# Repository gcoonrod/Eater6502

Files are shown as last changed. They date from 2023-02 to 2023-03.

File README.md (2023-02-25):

<!--
 Copyright 2023 Greg Coonrod
 
 Licensed under the Apache License, Version 2.0 (the "License");
 you may not use this file except in compliance with the License.
 You may obtain a copy of the License at
 
     http://www.apache.org/licenses/LICENSE-2.0
 
 Unless required by applicable law or agreed to in writing, software
 distributed under the License is distributed on an "AS IS" BASIS,
 WITHOUT WARRANTIES OR CONDITIONS OF ANY KIND, either express or implied.
 See the License for the specific language governing permissions and
 limitations under the License.
-->

# Eater 6502 - Computer Build

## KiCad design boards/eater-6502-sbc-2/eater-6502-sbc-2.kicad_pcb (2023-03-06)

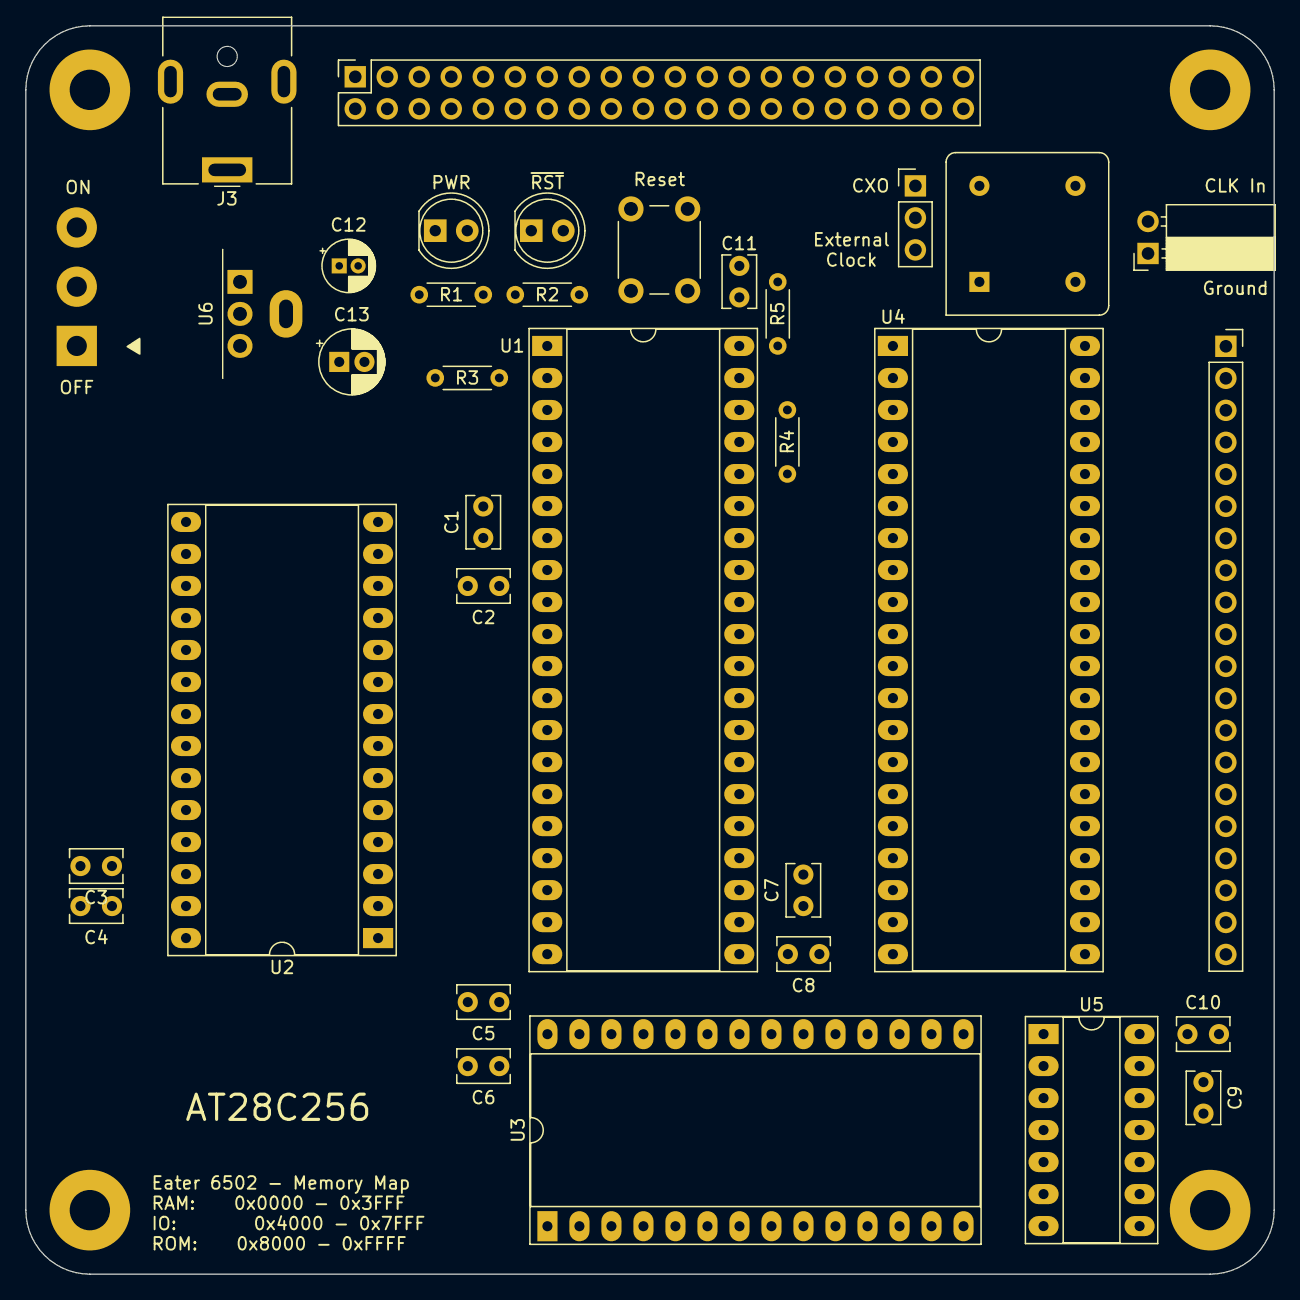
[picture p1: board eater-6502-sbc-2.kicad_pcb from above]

Board: 2 copper layers, 99.1 x 99.1 mm, 39 parts (0 on the bottom side), 70 nets, no tracks yet.

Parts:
C1, C3, C5, C7, C9: 1u; C_Rect_L4.0mm_W2.5mm_P2.50mm
C2, C4, C6, C8, C10, C11: 100n; C_Rect_L4.0mm_W2.5mm_P2.50mm
C12: 0u33; CP_Radial_D4.0mm_P1.50mm
C13: 10u; CP_Radial_D5.0mm_P2.00mm
D1: LED_PWR; LED_D5.0mm
D2: LED_RST; LED_D5.0mm
H1, H2, H3, H4: M3; MountingHole_3.2mm_M3_Pad
HS1: Heatsink; Heatsink_AAVID_576802B03900G
J1: HDR_EXT_CLK; PinSocket_1x02_P2.54mm_Horizontal
J2: HDR_CPU_BUS; PinSocket_2x20_P2.54mm_Vertical
J3: Jack-DC; BarrelJack_CUI_PJ-063AH_Horizontal
J4: HDR_PIO_PORT; PinSocket_1x20_P2.54mm_Vertical
JP1: JMP_CLK; PinHeader_1x03_P2.54mm_Vertical
R1, R2: 470; R_Axial_DIN0204_L3.6mm_D1.6mm_P5.08mm_Horizontal
R3, R4, R5: 1k; R_Axial_DIN0204_L3.6mm_D1.6mm_P5.08mm_Horizontal
SW1: SW_RESET; SW_PUSH_6mm
SW2: SW_PWR; Button_Switch_SPST_NKK_CS12ANW03
U1: W65C02SxP; DIP-40_W15.24mm_Socket_LongPads
U2: 28C256; DIP-28_W15.24mm_Socket_LongPads
U3: KM62256CLP; DIP-28_W15.24mm_Socket_LongPads
U4: W65C22NxP; DIP-40_W15.24mm_Socket_LongPads
U5: 74HC132; DIP-14_W7.62mm_Socket_LongPads
U6: MC7805; TO-220-3_Vertical
X1: 14 MHz; Oscillator_DIP-8

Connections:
/A0: J2.17, U1.9 (A0), U2.10 (A0), U3.10 (A0), U4.38 (RS0)
/A1: J2.19, U1.10 (A1), U2.9 (A1), U3.9 (A1), U4.37 (RS1)
/A2: J2.21, U1.11 (A2), U2.8 (A2), U3.8 (A2), U4.36 (RS2)
/A3: J2.23, U1.12 (A3), U2.7 (A3), U3.7 (A3), U4.35 (RS3)
/A4: J2.25, U1.13 (A4), U2.6 (A4), U3.6 (A4)
/A5: J2.27, U1.14 (A5), U2.5 (A5), U3.5 (A5)
/A6: J2.29, U1.15 (A6), U2.4 (A6), U3.4 (A6)
/A7: J2.31, U1.16 (A7), U2.3 (A7), U3.3 (A7)
/A8: J2.33, U1.17 (A8), U2.25 (A8), U3.25 (A8)
/A9: J2.35, U1.18 (A9), U2.24 (A9), U3.24 (A9)
/A10: J2.37, U1.19 (A10), U2.21 (A10), U3.21 (A10)
/A11: J2.39, U1.20 (A11), U2.23 (A11), U3.23 (A11)
/A12: J2.38, U1.22 (A12), U2.2 (A12), U3.2 (A12)
/A13: J2.36, U1.23 (A13), U2.26 (A13), U3.26 (A13), U4.24 (CS1)
/A14: J2.34, U1.24 (A14), U2.1 (A14), U3.1 (A14), U3.22 (~OE), U5.5
/A15: J2.32, U1.25 (A15), U5.1, U5.2
/ADDR_~HI: U2.20 (~CS), U5.3, U5.4, U5.9
/BE: J2.10, R4.1, U1.36 (BE)
/CA1: J4.9, U4.40 (CA1)
/CA2: J4.10, U4.39 (CA2)
/CB1: J4.11, U4.18 (CB1)
/CB2: J4.12, U4.19 (CB2)
/CLK: J2.8, JP1.2 (C), U1.37 (ϕ0), U4.25 (ϕ2), U5.10
/CLK2: J2.4, U1.39 (ϕ2)
/CXO: JP1.1 (A), X1.5 (OUT)
/D0: J2.16, U1.33 (D0), U2.11 (D0), U3.11 (Q0), U4.33 (D0)
/D1: J2.18, U1.32 (D1), U2.12 (D1), U3.12 (Q1), U4.32 (D1)
/D2: J2.20, U1.31 (D2), U2.13 (D2), U3.13 (Q2), U4.31 (D2)
/D3: J2.22, U1.30 (D3), U2.15 (D3), U3.15 (Q3), U4.30 (D3)
/D4: J2.24, U1.29 (D4), U2.16 (D4), U3.16 (Q4), U4.29 (D4)
/D5: J2.26, U1.28 (D5), U2.17 (D5), U3.17 (Q5), U4.28 (D5)
/D6: J2.28, U1.27 (D6), U2.18 (D6), U3.18 (Q6), U4.27 (D6)
/D7: J2.30, U1.26 (D7), U2.19 (D7), U3.19 (Q7), U4.26 (D7)
/EXT_CLK: J1.2, JP1.3 (B)
/PA0: J4.1, U4.2 (PA0)
/PA1: J4.2, U4.3 (PA1)
/PA2: J4.3, U4.4 (PA2)
/PA3: J4.4, U4.5 (PA3)
/PA4: J4.5, U4.6 (PA4)
/PA5: J4.6, U4.7 (PA5)
/PA6: J4.7, U4.8 (PA6)
/PA7: J4.8, U4.9 (PA7)
/PB0: J4.13, U4.10 (PB0)
/PB1: J4.14, U4.11 (PB1)
/PB2: J4.15, U4.12 (PB2)
/PB3: J4.16, U4.13 (PB3)
/PB4: J4.17, U4.14 (PB4)
/PB5: J4.18, U4.15 (PB5)
/PB6: J4.19, U4.16 (PB6)
/PB7: J4.20, U4.17 (PB7)
/RAM_~EN: U3.20 (~CS), U5.8
/RDY: J2.3, R3.2, U1.2 (RDY)
/R/~W: J2.14, U1.34 (R/~W), U3.27 (~WE), U4.22 (R/~W)
/SYNC: J2.13, U1.7 (SYNC)
/VIA_~CS2: U4.23 (~CS2), U5.6
/~CLK: J2.5, U1.3 (ϕ1)
/~IRQ: J2.7, U1.4 (~IRQ), U4.21 (~IRQ)
/~ML: J2.9, U1.5 (~ML)
/~NMI: J2.11, U1.6 (~NMI)
/~RES: J2.2, U1.40 (~RES), U4.34 (~RES), U5.12, U5.13
/~RST: C11.2, R5.2, SW1.2
/~SO: J2.6, U1.38 (~SO)
/~VP: J2.1, U1.1 (~VP)
GND: C1.2, C2.2, C3.2, C4.2, C5.2, C6.2, C7.2, C8.2, C9.2, C10.2, C11.1, C12.2, C13.2, H1.1, H2.1, H3.1, H4.1, J1.1, J2.40, J3.2, R1.2, R2.2, SW1.1, U1.21 (VSS), U2.14 (GND), U2.22 (~OE), U3.14 (GND), U4.1 (VSS), U5.7 (GND), U6.2 (GND), X1.4 (GND)
unnamed: D1.1 (K), R1.1
unnamed: D2.1 (K), R2.1
unnamed: D2.2 (A), U5.11
unnamed: J3.1, SW2.2 (B)
VCC: C1.1, C2.1, C3.1, C4.1, C5.1, C6.1, C7.1, C8.1, C9.1, C10.1, C13.1, D1.2 (A), J2.15, R3.1, R4.2, R5.1, U1.8 (VDD), U2.27 (~WE), U2.28 (VCC), U3.28 (VCC), U4.20 (VCC), U5.14 (VCC), U6.3 (VO), X1.8 (Vcc)
VDC: C12.1, SW2.3 (C), U6.1 (VI)

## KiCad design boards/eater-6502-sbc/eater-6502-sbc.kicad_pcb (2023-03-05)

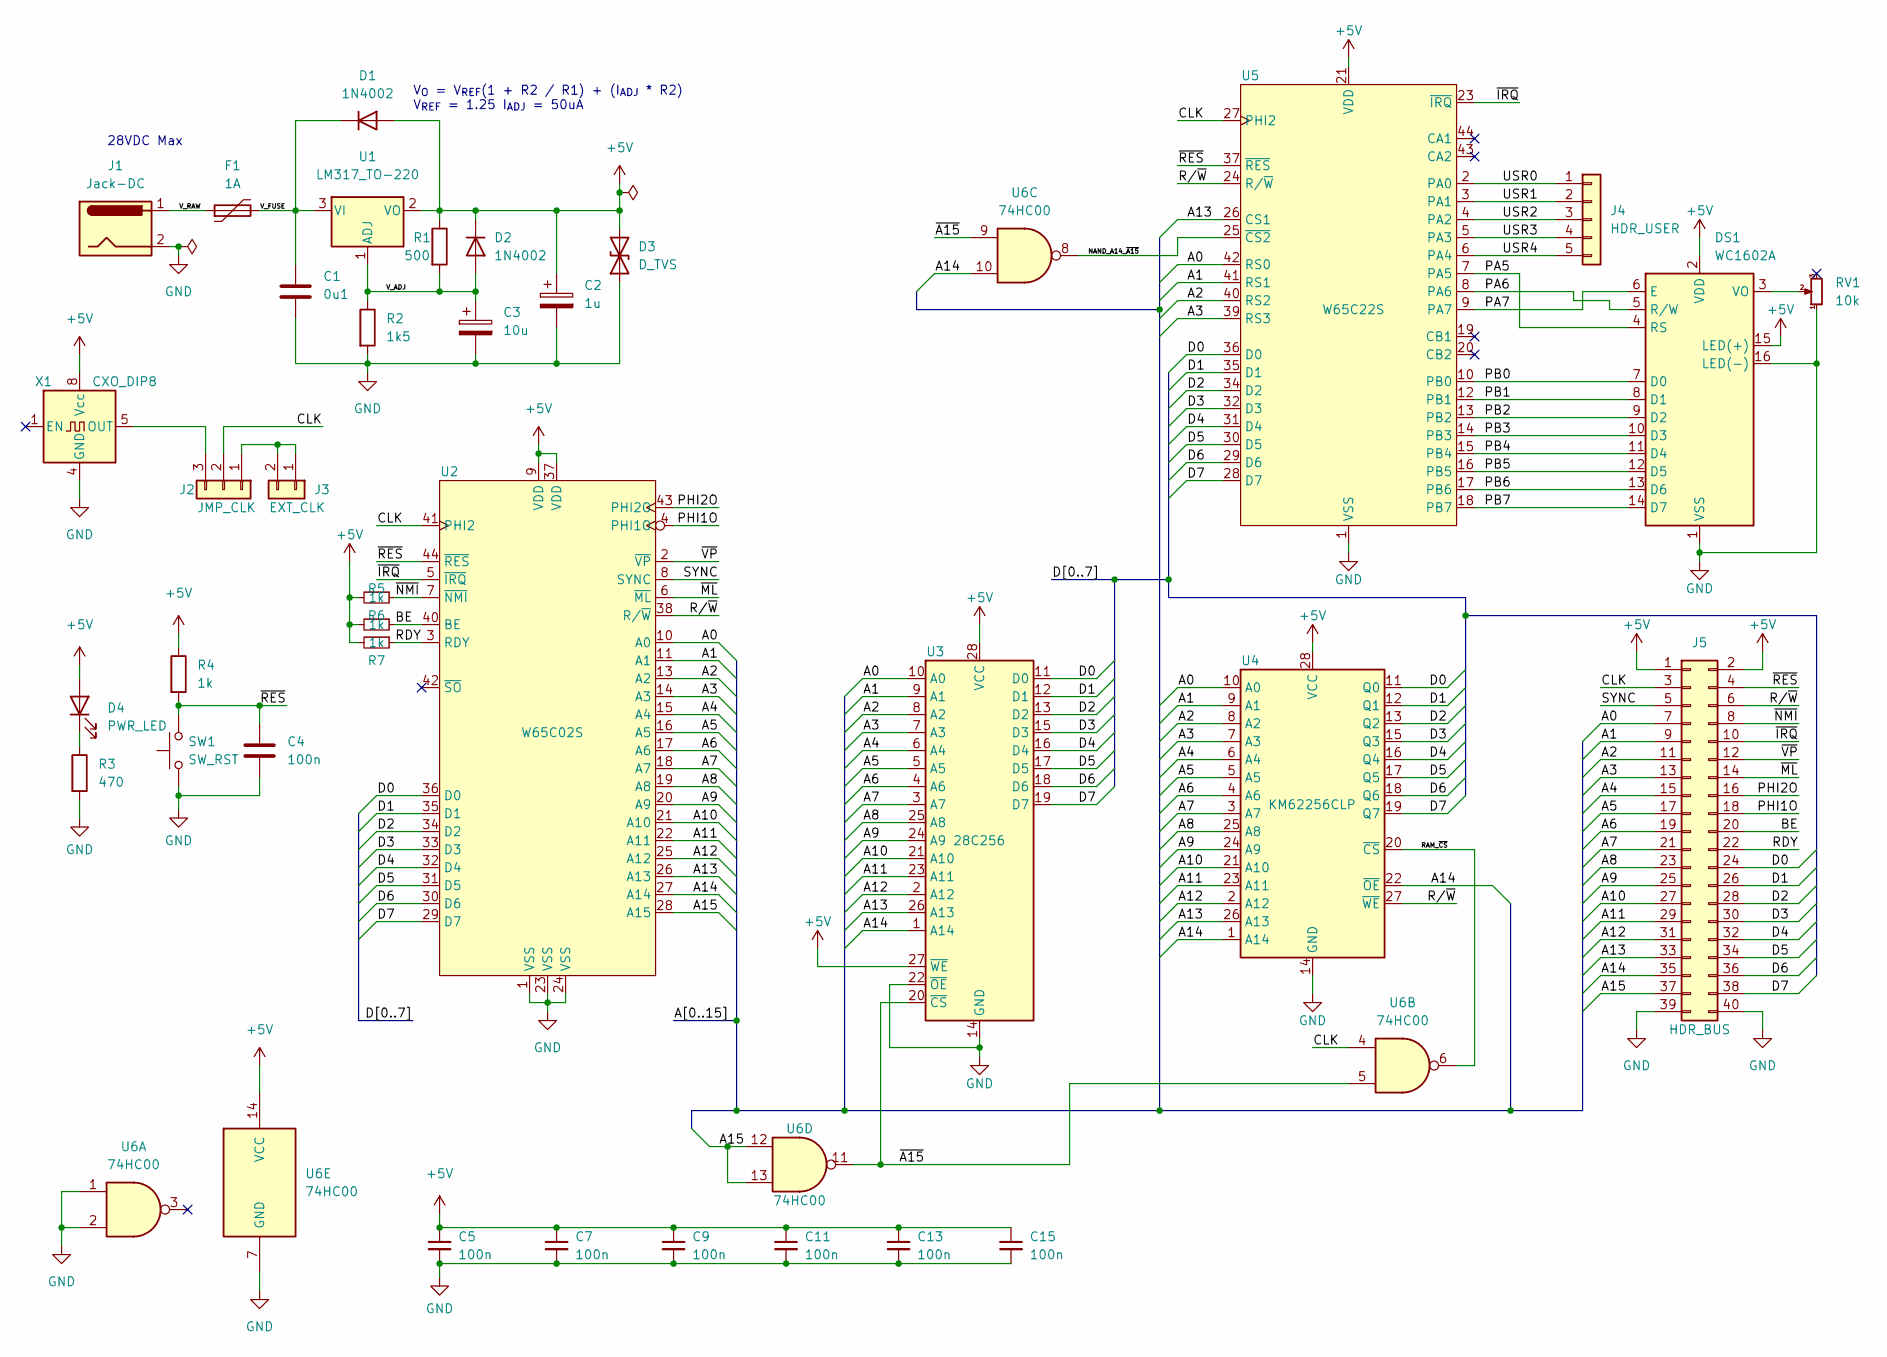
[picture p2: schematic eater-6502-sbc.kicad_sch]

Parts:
C1: 0u1; C_Disc_D3.4mm_W2.1mm_P2.50mm
C2: 1u; CP_Radial_D4.0mm_P1.50mm
C3: 10u; CP_Radial_D5.0mm_P2.00mm
C4, C5, C7, C9, C11, C13, C15: 100n; C_Disc_D3.4mm_W2.1mm_P2.50mm
D1, D2: 1N4002; D_DO-41_SOD81_P10.16mm_Horizontal
D3: D_TVS; D_DO-41_SOD81_P7.62mm_Horizontal
D4: PWR_LED; LED_D5.0mm
DS1: WC1602A
F1: 1A; Fuse_BelFuse_0ZRE0005FF_L8.3mm_W3.8mm
J1: Jack-DC; BarrelJack_CUI_PJ-063AH_Horizontal
J2: JMP_CLK; PinHeader_1x03_P2.54mm_Vertical
J3: EXT_CLK; PinSocket_1x02_P2.54mm_Vertical
J4: HDR_USER; PinSocket_1x05_P2.54mm_Vertical
J5: HDR_BUS; PinSocket_2x20_P2.54mm_Vertical
R1: 500; R_Axial_DIN0207_L6.3mm_D2.5mm_P10.16mm_Horizontal
R2: 1k5; R_Axial_DIN0207_L6.3mm_D2.5mm_P10.16mm_Horizontal
R3: 470; R_Axial_DIN0204_L3.6mm_D1.6mm_P5.08mm_Horizontal
R4, R5, R6, R7: 1k; R_Axial_DIN0204_L3.6mm_D1.6mm_P5.08mm_Horizontal
RV1: 10k; Potentiometer_Bourns_3266W_Vertical
SW1: SW_RST; SW_PUSH_6mm
U1: LM317_TO-220; TO-220-3_Vertical; Manufacturer Part Number LM317KCS
U2: W65C02S; PLCC-44_THT-Socket; Manufacturer Part Number W65C02S6TPLG-14
U3: 28C256; DIP_Socket-28_W11.9_W12.7_W15.24_W17.78_W18.5_3M_228-1277-0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; Manufacturer Part Number 28-6554-10
U4: KM62256CLP; DIP-28_W15.24mm_Socket_LongPads; Manufacturer Part Number AS6C62256-55PCN
U5: W65C22S; PLCC-44_THT-Socket; Manufacturer Part Number W65C22S6TPLG-14
U6: 74HC00; DIP-14_W7.62mm_LongPads
X1: CXO_DIP8; Oscillator_DIP-8_LargePads

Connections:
+5V: C2.1, C5.1, C7.1, C9.1, C11.1, C13.1, C15.1, D1.2 (A), D2.1 (K), D3.2 (A2), D4.2 (A), DS1.2 (VDD), DS1.15 (LED(+)), J5.1, J5.2, R1.1, R4.1, R5.2, R6.2, R7.2, U1.2 (VO), U2.9 (VDD), U2.37 (VDD), U3.27 (~WE), U3.28 (VCC), U4.28 (VCC), U5.21 (VDD), U6.14 (VCC), X1.8 (Vcc)
/A0: J5.7, U2.10 (A0), U3.10 (A0), U4.10 (A0), U5.42 (RS0)
/A1: J5.9, U2.11 (A1), U3.9 (A1), U4.9 (A1), U5.41 (RS1)
/A2: J5.11, U2.13 (A2), U3.8 (A2), U4.8 (A2), U5.40 (RS2)
/A3: J5.13, U2.14 (A3), U3.7 (A3), U4.7 (A3), U5.39 (RS3)
/A4: J5.15, U2.15 (A4), U3.6 (A4), U4.6 (A4)
/A5: J5.17, U2.16 (A5), U3.5 (A5), U4.5 (A5)
/A6: J5.19, U2.17 (A6), U3.4 (A6), U4.4 (A6)
/A7: J5.21, U2.18 (A7), U3.3 (A7), U4.3 (A7)
/A8: J5.23, U2.19 (A8), U3.25 (A8), U4.25 (A8)
/A9: J5.25, U2.20 (A9), U3.24 (A9), U4.24 (A9)
/A10: J5.27, U2.21 (A10), U3.21 (A10), U4.21 (A10)
/A11: J5.29, U2.22 (A11), U3.23 (A11), U4.23 (A11)
/A12: J5.31, U2.25 (A12), U3.2 (A12), U4.2 (A12)
/A13: J5.33, U2.26 (A13), U3.26 (A13), U4.26 (A13), U5.26 (CS1)
/A14: J5.35, U2.27 (A14), U3.1 (A14), U4.1 (A14), U4.22 (~OE), U6.10
/A15: J5.37, U2.28 (A15), U6.12, U6.13
/BE: J5.20, R6.1, U2.40 (BE)
/CLK: J2.2, J5.3, U2.41 (PHI2), U5.27 (PHI2), U6.4
/D0: J5.24, U2.36 (D0), U3.11 (D0), U4.11 (Q0), U5.36 (D0)
/D1: J5.26, U2.35 (D1), U3.12 (D1), U4.12 (Q1), U5.35 (D1)
/D2: J5.28, U2.34 (D2), U3.13 (D2), U4.13 (Q2), U5.34 (D2)
/D3: J5.30, U2.33 (D3), U3.15 (D3), U4.15 (Q3), U5.32 (D3)
/D4: J5.32, U2.32 (D4), U3.16 (D4), U4.16 (Q4), U5.31 (D4)
/D5: J5.34, U2.31 (D5), U3.17 (D5), U4.17 (Q5), U5.30 (D5)
/D6: J5.36, U2.30 (D6), U3.18 (D6), U4.18 (Q6), U5.29 (D6)
/D7: J5.38, U2.29 (D7), U3.19 (D7), U4.19 (Q7), U5.28 (D7)
/NAND_A14_~A15: U5.25 (~CS2), U6.8
/PA5: DS1.4 (RS), U5.7 (PA5)
/PA6: DS1.5 (R/W), U5.8 (PA6)
/PA7: DS1.6 (E), U5.9 (PA7)
/PB0: DS1.7 (D0), U5.10 (PB0)
/PB1: DS1.8 (D1), U5.12 (PB1)
/PB2: DS1.9 (D2), U5.13 (PB2)
/PB3: DS1.10 (D3), U5.14 (PB3)
/PB4: DS1.11 (D4), U5.15 (PB4)
/PB5: DS1.12 (D5), U5.16 (PB5)
/PB6: DS1.13 (D6), U5.17 (PB6)
/PB7: DS1.14 (D7), U5.18 (PB7)
/PHI1O: J5.18, U2.4 (PHI1O)
/PHI2O: J5.16, U2.43 (PHI2O)
/RAM_~CS: U4.20 (~CS), U6.6
/RDY: J5.22, R7.1, U2.3 (RDY)
/R/~W: J5.6, U2.38 (R/~W), U4.27 (~WE), U5.24 (R/~W)
/SYNC: J5.5, U2.8 (SYNC)
/USR0: J4.1, U5.2 (PA0)
/USR1: J4.2, U5.3 (PA1)
/USR2: J4.3, U5.4 (PA2)
/USR3: J4.4, U5.5 (PA3)
/USR4: J4.5, U5.6 (PA4)
/V_ADJ: C3.1, D2.2 (A), R1.2, R2.1, U1.1 (ADJ)
/V_FUSE: C1.1, D1.1 (K), F1.2, U1.3 (VI)
/V_RAW: F1.1, J1.1
/~A15: U3.20 (~CS), U6.5, U6.9, U6.11
/~IRQ: J5.10, U2.5 (~IRQ), U5.23 (~IRQ)
/~ML: J5.14, U2.6 (~ML)
/~NMI: J5.8, R5.1, U2.7 (~NMI)
/~RES: C4.1, J5.4, R4.2, SW1.2, U2.44 (~RES), U5.37 (~RES)
/~VP: J5.12, U2.2 (~VP)
GND: C1.2, C2.2, C3.2, C4.2, C5.2, C7.2, C9.2, C11.2, C13.2, C15.2, D3.1 (A1), DS1.1 (VSS), DS1.16 (LED(-)), J1.2, J5.39, J5.40, R2.2, R3.2, RV1.1, SW1.1, U2.1 (VSS), U2.23 (VSS), U2.24 (VSS), U3.14 (GND), U3.22 (~OE), U4.14 (GND), U5.1 (VSS), U6.1, U6.2, U6.7 (GND), X1.4 (GND)
unnamed: D4.1 (K), R3.1
unnamed: DS1.3 (VO), RV1.2
unnamed: J2.1, J3.1, J3.2
unnamed: J2.3, X1.5 (OUT)

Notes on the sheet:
V_{O} = V_{REF}(1 + R2 / R1) + (I_{ADJ} * R2) V_{REF} = 1.25 I_{ADJ} = 50uA
28VDC Max

Board: 2 copper layers, 37 parts (0 on the bottom side), 64 nets, no tracks yet.

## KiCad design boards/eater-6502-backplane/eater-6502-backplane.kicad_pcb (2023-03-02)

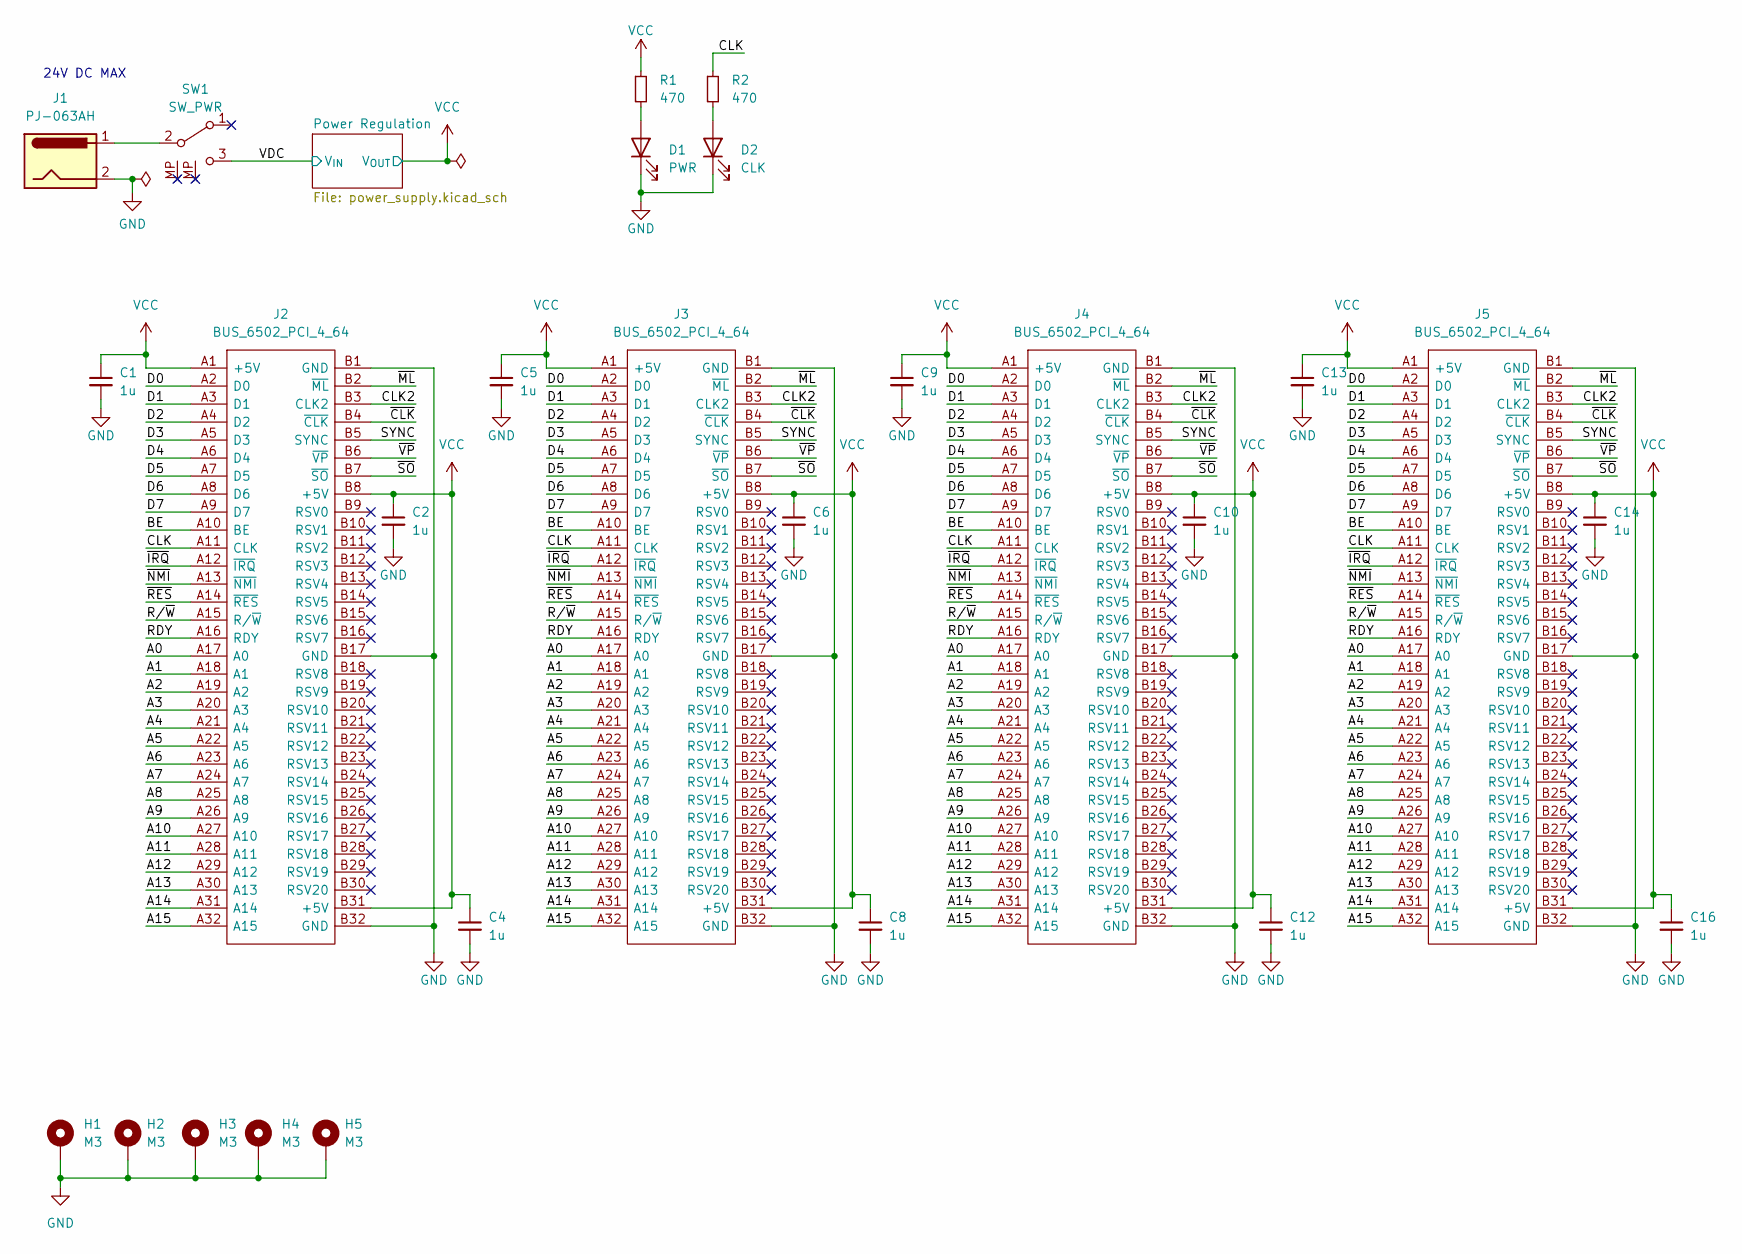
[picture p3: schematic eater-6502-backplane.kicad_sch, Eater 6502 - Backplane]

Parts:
C1, C2, C4, C5, C6, C8, C9, C10, C12, C13, C14, C16: 1u; C_Rect_L4.0mm_W2.5mm_P2.50mm; Manufacturer Part Number FG18X5R1H105KRT06
D1: PWR; LED_D5.0mm
D2: CLK; LED_D5.0mm
H1, H2, H3, H4, H5: M3; MountingHole_3.2mm_M3_Pad_Via
J1: PJ-063AH; BarrelJack_CUI_PJ-063AH_Horizontal; Manufacturer Part Number PJ-063AH
J2, J3, J4, J5: BUS_6502_PCI_4_64; 877159100 PCIe x4; Mouser Part Number 538-87715-9100
R1, R2: 470; R_Axial_DIN0207_L6.3mm_D2.5mm_P7.62mm_Horizontal; Manufacturer Part Number RNF14FTD470R
SW1: SW_PWR; Button_Switch_Dailywell_SPDT; Manufacturer Part Number 5MS1S102AM6QES

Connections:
/A0: J2.A17 (A0), J3.A17 (A0), J4.A17 (A0), J5.A17 (A0)
/A1: J2.A18 (A1), J3.A18 (A1), J4.A18 (A1), J5.A18 (A1)
/A2: J2.A19 (A2), J3.A19 (A2), J4.A19 (A2), J5.A19 (A2)
/A3: J2.A20 (A3), J3.A20 (A3), J4.A20 (A3), J5.A20 (A3)
/A4: J2.A21 (A4), J3.A21 (A4), J4.A21 (A4), J5.A21 (A4)
/A5: J2.A22 (A5), J3.A22 (A5), J4.A22 (A5), J5.A22 (A5)
/A6: J2.A23 (A6), J3.A23 (A6), J4.A23 (A6), J5.A23 (A6)
/A7: J2.A24 (A7), J3.A24 (A7), J4.A24 (A7), J5.A24 (A7)
/A8: J2.A25 (A8), J3.A25 (A8), J4.A25 (A8), J5.A25 (A8)
/A9: J2.A26 (A9), J3.A26 (A9), J4.A26 (A9), J5.A26 (A9)
/A10: J2.A27 (A10), J3.A27 (A10), J4.A27 (A10), J5.A27 (A10)
/A11: J2.A28 (A11), J3.A28 (A11), J4.A28 (A11), J5.A28 (A11)
/A12: J2.A29 (A12), J3.A29 (A12), J4.A29 (A12), J5.A29 (A12)
/A13: J2.A30 (A13), J3.A30 (A13), J4.A30 (A13), J5.A30 (A13)
/A14: J2.A31 (A14), J3.A31 (A14), J4.A31 (A14), J5.A31 (A14)
/A15: J2.A32 (A15), J3.A32 (A15), J4.A32 (A15), J5.A32 (A15)
/BE: J2.A10 (BE), J3.A10 (BE), J4.A10 (BE), J5.A10 (BE)
/CLK: J2.A11 (CLK), J3.A11 (CLK), J4.A11 (CLK), J5.A11 (CLK), R2.1
/CLK2: J2.B3 (CLK2), J3.B3 (CLK2), J4.B3 (CLK2), J5.B3 (CLK2)
/D0: J2.A2 (D0), J3.A2 (D0), J4.A2 (D0), J5.A2 (D0)
/D1: J2.A3 (D1), J3.A3 (D1), J4.A3 (D1), J5.A3 (D1)
/D2: J2.A4 (D2), J3.A4 (D2), J4.A4 (D2), J5.A4 (D2)
/D3: J2.A5 (D3), J3.A5 (D3), J4.A5 (D3), J5.A5 (D3)
/D4: J2.A6 (D4), J3.A6 (D4), J4.A6 (D4), J5.A6 (D4)
/D5: J2.A7 (D5), J3.A7 (D5), J4.A7 (D5), J5.A7 (D5)
/D6: J2.A8 (D6), J3.A8 (D6), J4.A8 (D6), J5.A8 (D6)
/D7: J2.A9 (D7), J3.A9 (D7), J4.A9 (D7), J5.A9 (D7)
/RDY: J2.A16 (RDY), J3.A16 (RDY), J4.A16 (RDY), J5.A16 (RDY)
/R/~W: J2.A15 (R/~W), J3.A15 (R/~W), J4.A15 (R/~W), J5.A15 (R/~W)
/SYNC: J2.B5 (SYNC), J3.B5 (SYNC), J4.B5 (SYNC), J5.B5 (SYNC)
/VDC: SW1.3 (C); also elsewhere on the board
/~CLK: J2.B4 (~CLK), J3.B4 (~CLK), J4.B4 (~CLK), J5.B4 (~CLK)
/~IRQ: J2.A12 (~IRQ), J3.A12 (~IRQ), J4.A12 (~IRQ), J5.A12 (~IRQ)
/~ML: J2.B2 (~ML), J3.B2 (~ML), J4.B2 (~ML), J5.B2 (~ML)
/~NMI: J2.A13 (~NMI), J3.A13 (~NMI), J4.A13 (~NMI), J5.A13 (~NMI)
/~RES: J2.A14 (~RES), J3.A14 (~RES), J4.A14 (~RES), J5.A14 (~RES)
/~SO: J2.B7 (~SO), J3.B7 (~SO), J4.B7 (~SO), J5.B7 (~SO)
/~VP: J2.B6 (~VP), J3.B6 (~VP), J4.B6 (~VP), J5.B6 (~VP)
GND: C1.2, C2.2, C4.2, C5.2, C6.2, C8.2, C9.2, C10.2, C12.2, C13.2, C14.2, C16.2, D1.1 (K), D2.1 (K), H1.1, H2.1, H3.1, H4.1, H5.1, J1.2, J2.B1 (GND), J2.B17 (GND), J2.B32 (GND), J3.B1 (GND), J3.B17 (GND), J3.B32 (GND), J4.B1 (GND), J4.B17 (GND), J4.B32 (GND), J5.B1 (GND), J5.B17 (GND), J5.B32 (GND); also elsewhere on the board
unnamed: D1.2 (A), R1.2
unnamed: D2.2 (A), R2.2
unnamed: J1.1, SW1.2 (B)
VCC: C1.1, C2.1, C4.1, C5.1, C6.1, C8.1, C9.1, C10.1, C12.1, C13.1, C14.1, C16.1, J2.A1 (+5V), J2.B8 (+5V), J2.B31 (+5V), J3.A1 (+5V), J3.B8 (+5V), J3.B31 (+5V), J4.A1 (+5V), J4.B8 (+5V), J4.B31 (+5V), J5.A1 (+5V), J5.B8 (+5V), J5.B31 (+5V), R1.1; also elsewhere on the board

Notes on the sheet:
24V DC MAX

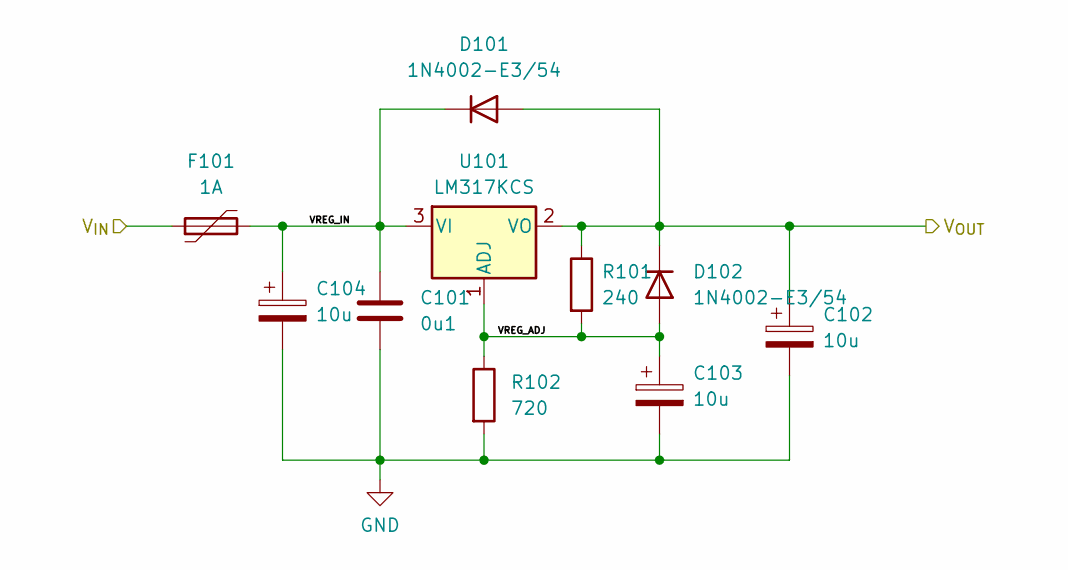
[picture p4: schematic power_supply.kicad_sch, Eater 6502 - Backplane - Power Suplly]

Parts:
C101: 0u1; C_Disc_D4.3mm_W1.9mm_P5.00mm; Manufacturer Part Number K104K15X7RF5TH5
C102, C103, C104: 10u; CP_Radial_D5.0mm_P2.00mm; Manufacturer Part Number 860010572002
D101, D102: 1N4002-E3/54; D_DO-41_SOD81_P10.16mm_Horizontal; Manufacturer Part Number 1N4002-E3/54
F101: 1A; Fuse_BelFuse_0ZRE0025FF_L9.6mm_W3.8mm; Manufacturer Part Number 0ZRM0050FF1E
R101: 240; R_Axial_DIN0207_L6.3mm_D2.5mm_P10.16mm_Horizontal; Manufacturer Part Number SFR2500002400FR500
R102: 720; R_Axial_DIN0207_L6.3mm_D2.5mm_P10.16mm_Horizontal; Manufacturer Part Number MFR-25FTF52-720R
U101: LM317KCS; TO-220-3_Vertical; Manufacturer Part Number LM317KCS

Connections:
/Power Regulation/VREG_ADJ: C103.1, D102.2 (A), R101.2, R102.1, U101.1 (ADJ)
/Power Regulation/VREG_IN: C101.1, C104.1, D101.1 (K), F101.2, U101.3 (VI)
/VDC: F101.1; also elsewhere on the board
GND: C101.2, C102.2, C103.2, C104.2, R102.2; also elsewhere on the board
VCC: C102.1, D101.2 (A), D102.1 (K), R101.1, U101.2 (VO); also elsewhere on the board

Board: 2 copper layers, 37 parts (0 on the bottom side), 45 nets, no tracks yet.

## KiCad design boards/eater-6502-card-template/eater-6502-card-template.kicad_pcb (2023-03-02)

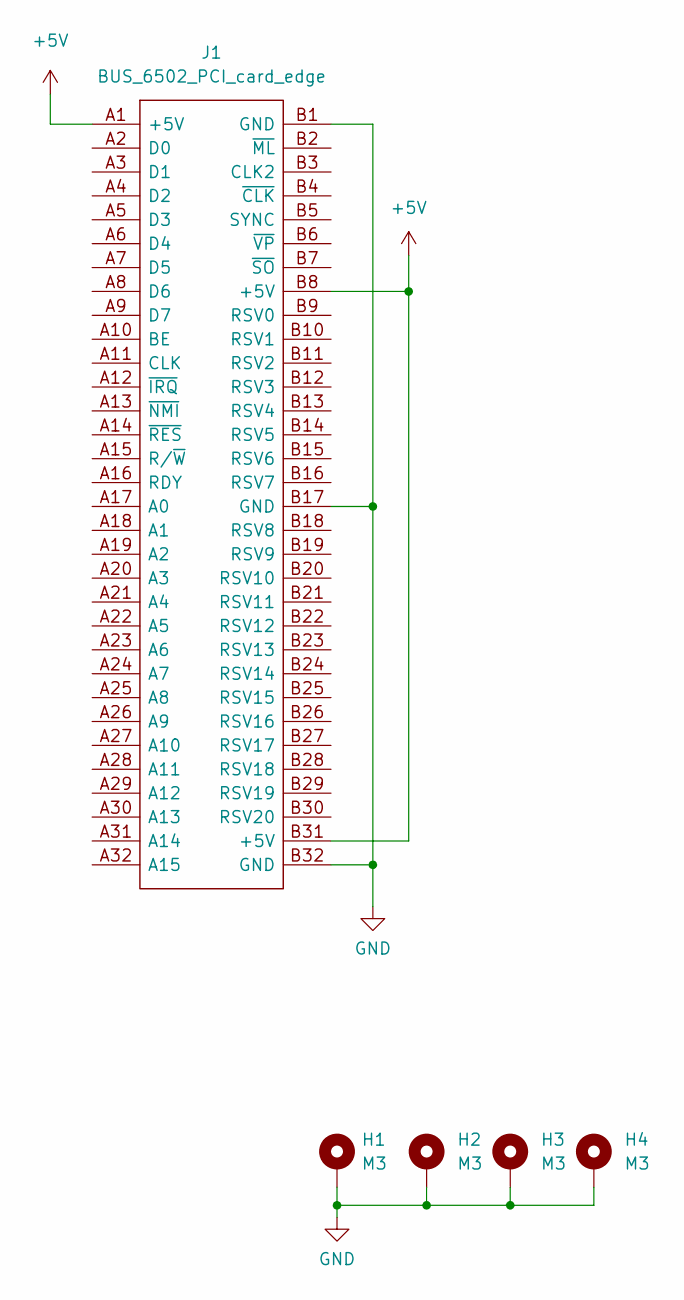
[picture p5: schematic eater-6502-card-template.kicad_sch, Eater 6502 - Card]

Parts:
H1, H2, H3, H4: M3; MountingHole_3.2mm_M3_Pad_Via
J1: BUS_6502_PCI_card_edge; BUS_Eater6502_PCI_x4; Mouser Part Number 538-87715-9100

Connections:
+5V: J1.A1 (+5V), J1.B8 (+5V), J1.B31 (+5V)
GND: H1.1, H2.1, H3.1, H4.1, J1.B1 (GND), J1.B17 (GND), J1.B32 (GND)

Board: 2 copper layers, 5 parts (1 on the bottom side), 2 nets, no tracks yet.

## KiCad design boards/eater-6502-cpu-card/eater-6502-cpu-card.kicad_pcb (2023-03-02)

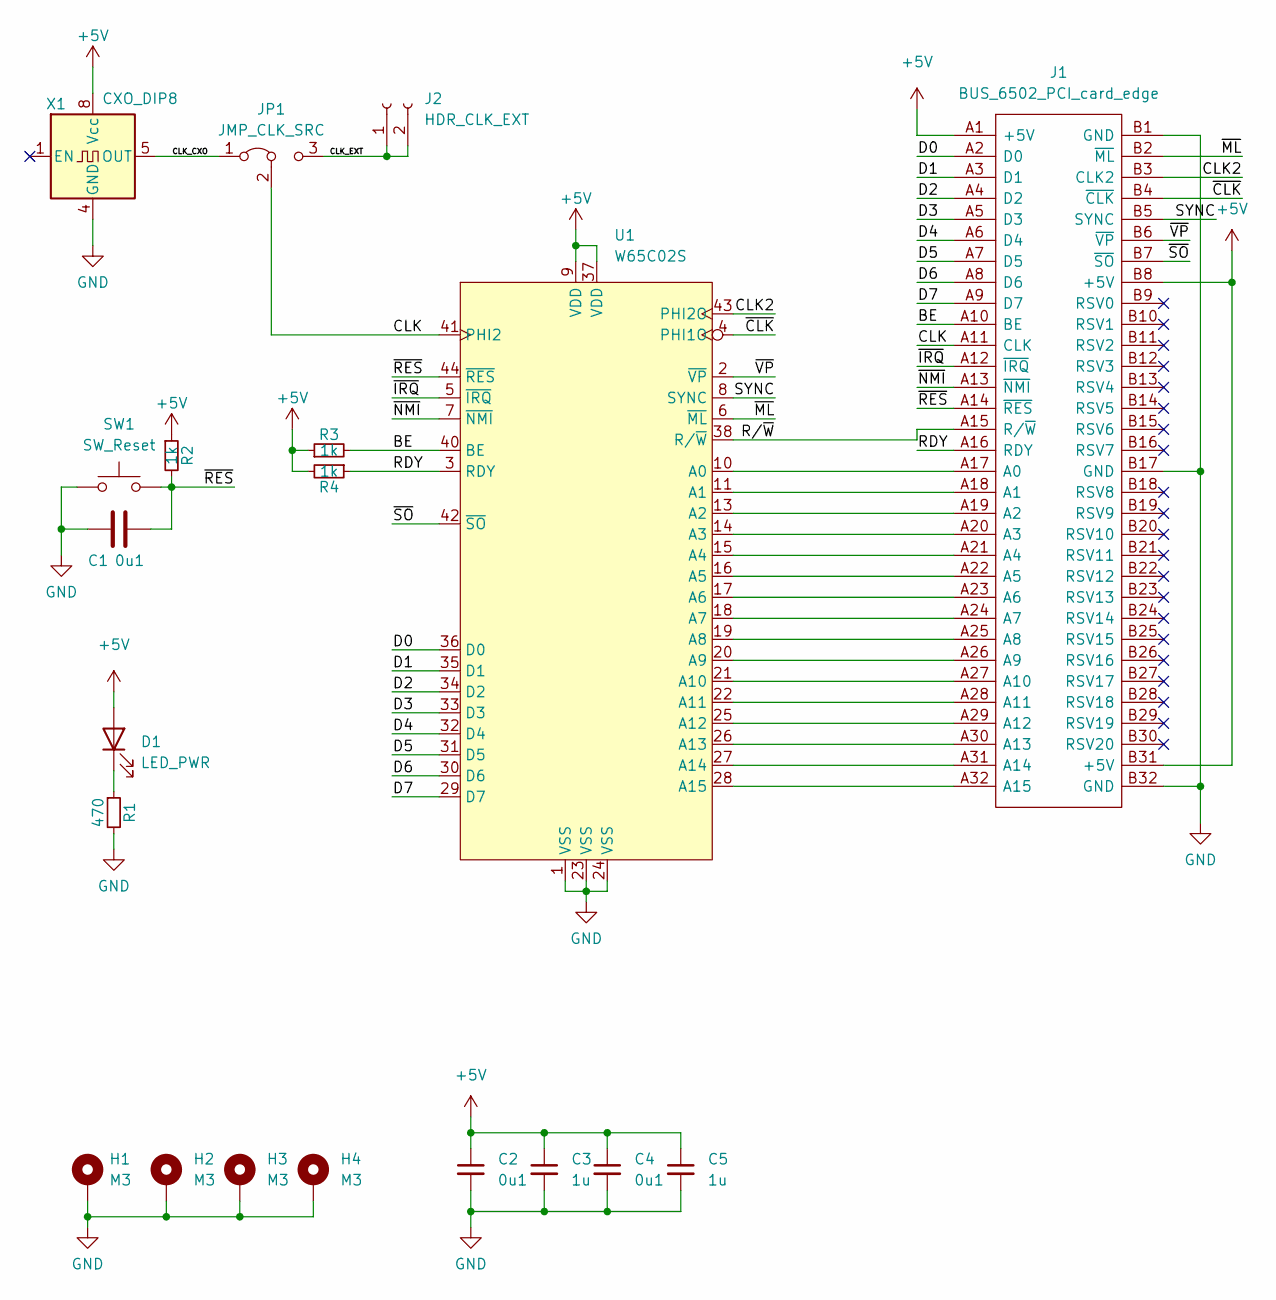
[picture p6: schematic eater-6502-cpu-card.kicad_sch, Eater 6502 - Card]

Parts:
C1, C2, C4: 0u1; C_Disc_D3.4mm_W2.1mm_P2.50mm
C3, C5: 1u; C_Disc_D3.4mm_W2.1mm_P2.50mm
D1: LED_PWR; LED_D3.0mm_Horizontal_O1.27mm_Z2.0mm
H1, H2, H3, H4: M3; MountingHole_3.2mm_M3_Pad_Via
J1: BUS_6502_PCI_card_edge; BUS_Eater6502_PCI_x4; Mouser Part Number 538-87715-9100
J2: HDR_CLK_EXT; PinSocket_1x02_P2.54mm_Horizontal
JP1: JMP_CLK_SRC; PinHeader_1x03_P2.54mm_Horizontal
R1: 470; R_Axial_DIN0204_L3.6mm_D1.6mm_P5.08mm_Horizontal
R2, R3, R4: 1k; R_Axial_DIN0204_L3.6mm_D1.6mm_P5.08mm_Horizontal
SW1: SW_Reset; SW_Tactile_SPST_Angled_PTS645Vx39-2LFS
U1: W65C02S; PLCC-44_THT-Socket
X1: CXO_DIP8; Oscillator_DIP-8

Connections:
+5V: C2.1, C3.1, C4.1, C5.1, D1.2 (A), J1.A1 (+5V), J1.B8 (+5V), J1.B31 (+5V), R2.1, R3.1, R4.2, U1.9 (VDD), U1.37 (VDD), X1.8 (Vcc)
/BE: J1.A10 (BE), R3.2, U1.40 (BE)
/CLK: J1.A11 (CLK), JP1.2 (C), U1.41 (PHI2)
/CLK2: J1.B3 (CLK2), U1.43 (PHI2O)
/CLK_CXO: JP1.1 (A), X1.5 (OUT)
/CLK_EXT: J2.1, J2.2, JP1.3 (B)
/D0: J1.A2 (D0), U1.36 (D0)
/D1: J1.A3 (D1), U1.35 (D1)
/D2: J1.A4 (D2), U1.34 (D2)
/D3: J1.A5 (D3), U1.33 (D3)
/D4: J1.A6 (D4), U1.32 (D4)
/D5: J1.A7 (D5), U1.31 (D5)
/D6: J1.A8 (D6), U1.30 (D6)
/D7: J1.A9 (D7), U1.29 (D7)
/RDY: J1.A16 (RDY), R4.1, U1.3 (RDY)
/R/~W: J1.A15 (R/~W), U1.38 (R/~W)
/SYNC: J1.B5 (SYNC), U1.8 (SYNC)
/~CLK: J1.B4 (~CLK), U1.4 (PHI1O)
/~IRQ: J1.A12 (~IRQ), U1.5 (~IRQ)
/~ML: J1.B2 (~ML), U1.6 (~ML)
/~NMI: J1.A13 (~NMI), U1.7 (~NMI)
/~RES: C1.2, J1.A14 (~RES), R2.2, SW1.2, U1.44 (~RES)
/~SO: J1.B7 (~SO), U1.42 (~SO)
/~VP: J1.B6 (~VP), U1.2 (~VP)
GND: C1.1, C2.2, C3.2, C4.2, C5.2, H1.1, H2.1, H3.1, H4.1, J1.B1 (GND), J1.B17 (GND), J1.B32 (GND), R1.2, SW1.1, U1.1 (VSS), U1.23 (VSS), U1.24 (VSS), X1.4 (GND)
unnamed: D1.1 (K), R1.1
unnamed: J1.A17 (A0), U1.10 (A0)
unnamed: J1.A23 (A6), U1.17 (A6)
unnamed: J1.A18 (A1), U1.11 (A1)
unnamed: J1.A19 (A2), U1.13 (A2)
unnamed: J1.A20 (A3), U1.14 (A3)
unnamed: J1.A21 (A4), U1.15 (A4)
unnamed: J1.A22 (A5), U1.16 (A5)
unnamed: J1.A24 (A7), U1.18 (A7)
unnamed: J1.A25 (A8), U1.19 (A8)
unnamed: J1.A26 (A9), U1.20 (A9)
unnamed: J1.A27 (A10), U1.21 (A10)
unnamed: J1.A28 (A11), U1.22 (A11)
unnamed: J1.A29 (A12), U1.25 (A12)
unnamed: J1.A30 (A13), U1.26 (A13)
unnamed: J1.A31 (A14), U1.27 (A14)
unnamed: J1.A32 (A15), U1.28 (A15)

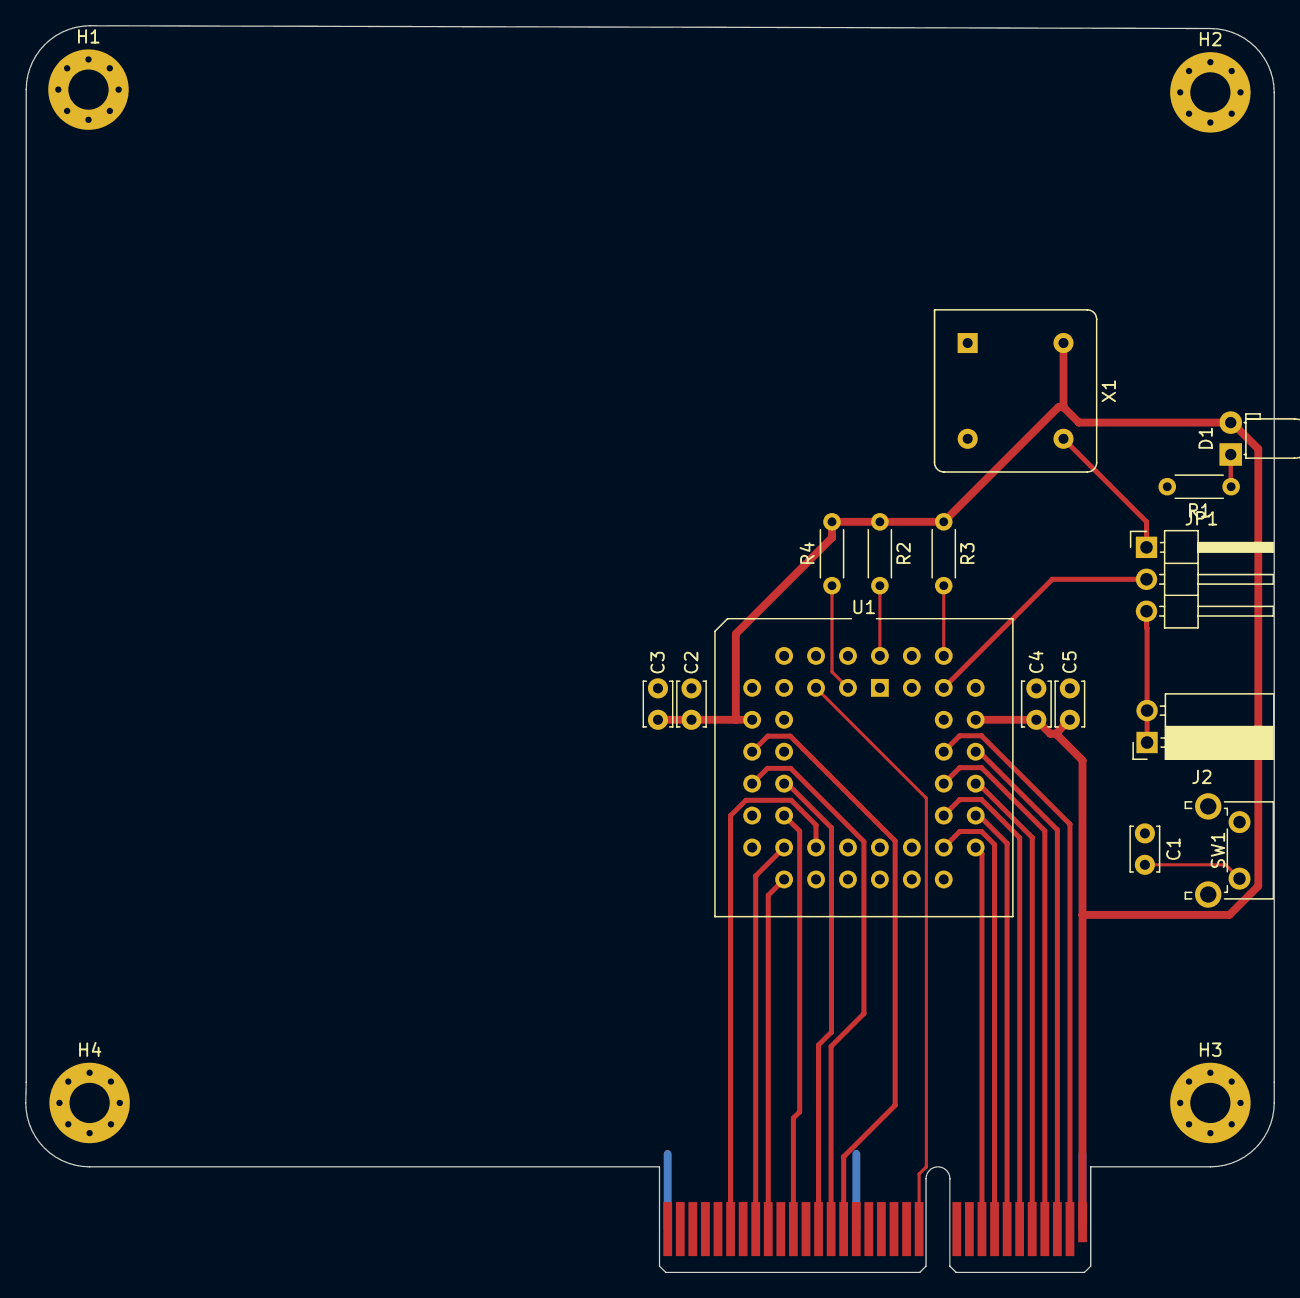
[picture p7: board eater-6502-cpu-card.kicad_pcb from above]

Board: 2 copper layers, 99.3 x 99.2 mm, 20 parts (1 on the bottom side), 42 nets.

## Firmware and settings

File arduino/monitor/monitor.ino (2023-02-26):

#define CLK 2
#define RWB 3

//const char ADDR[] = {22, 24, 26, 28, 30, 32, 34, 36, 38, 40, 42, 44, 46, 48, 50, 52};
const char ADDR[] = {52, 50, 48, 46, 44, 42, 40, 38, 36, 34, 32, 30, 28, 26, 24, 22};
//const char DATA[] = {39, 41, 43, 45, 47, 49, 51, 53};
const char DATA[] = {53, 51, 49, 47, 45, 43, 41, 39};

void setup(){
    pinMode(CLK, INPUT);
    pinMode(RWB, INPUT);
	for (int n = 0; n < 16; n++) {
        pinMode(ADDR[n], INPUT);
    }

    for (int i = 0; i < 8; i++) {
        pinMode(DATA[i], INPUT);
    }

    attachInterrupt(digitalPinToInterrupt(CLK), onClock, RISING);

    Serial.begin(115200);
}

void onClock(){
    char output[15];
    unsigned int address = 0;
	for (int i = 0; i < 16; i++) {
        int bit = digitalRead(ADDR[i]) ?  1 : 0;
        Serial.print(bit);
        address = (address << 1) + bit;
    }
    Serial.print("   ");

    unsigned int data = 0;
    for (int i = 0; i < 8; i++) {
        int bit = digitalRead(DATA[i]) ?  1 : 0;
        Serial.print(bit);
        data = (data << 1) + bit;
    }

    char rwbState = digitalRead(RWB) ? 'r' : 'W';

    sprintf(output, "  %04x  %c %02x", address, rwbState, data);
    Serial.print(output);
    Serial.println();
}

void loop(){

}

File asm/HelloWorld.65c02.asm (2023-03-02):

.target "65c02"
.format "bin"

; 65C22 Addresses
PORTB   .equ $6000
PORTA   .equ $6001
DDRB    .equ $6002
DDRA    .equ $6003

; HD44780U Control Signal masks
DISP_E  .equ %10000000
DISP_RW .equ %01000000
DISP_RS .equ %00100000

.org $fffc      ; Initialize Reset Vector
.word start
.word $0000

.org $8000
start:
    ldx #$ff    ; Initialize stack to 01ff
    txs

w65c22_init:
    lda #$ff    ; Set all Port B pins to output 
    sta DDRB
    lda #$e0    ; Set 3 most significant bits of Port A to outputs
    sta DDRA

lcd_init:
    lda #%00111000  ; Set 8 bit mode, 2 line display, 5x8 font
    jsr lcd_instruction
    lda #%00001110  ; Set display on, cursor on, blink off
    jsr lcd_instruction
    lda #%00000110  ; Increment and shift cursor, don't shift display
    jsr lcd_instruction

print_hello:
    lda #"H"    ; Send H
    jsr lcd_print_char
    lda #"e"
    jsr lcd_print_char
    lda #"l"
    jsr lcd_print_char
    lda #"l"
    jsr lcd_print_char
    lda #"o"
    jsr lcd_print_char
    lda #","
    jsr lcd_print_char
    lda #" "
    jsr lcd_print_char
    lda #"W"
    jsr lcd_print_char
    lda #"o"
    jsr lcd_print_char
    lda #"r"
    jsr lcd_print_char
    lda #"l"
    jsr lcd_print_char
    lda #"d"
    jsr lcd_print_char
    lda #"!"
    jsr lcd_print_char
    
    
wait_loop:
    nop
    jmp wait_loop

lcd_instruction:
    pha
    sta PORTB

    lda #0      ; Clear RS/RW/E bits
    sta PORTA

    lda #DISP_E ; Set display enable high
    sta PORTA
    lda #0      ; Set display enable low
    sta PORTA
    pla
    rts

lcd_print_char:
    pha
    sta PORTB

    lda #DISP_RS      ; Set RS, Clear RW/E bits
    sta PORTA

    lda #(DISP_E | DISP_RS) ; Set display enable and register select high
    sta PORTA
    lda #DISP_RS      ; Set display enable low
    sta PORTA
    pla
    rts

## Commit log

2023-03-02 Started multiple board layouts
    [eater-6502-backplane.kicad_pcb, eater-6502-backplane.kicad_sch, eater-6502-card-template.kicad_pcb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]
2023-03-05 SBC design 2 start
    [eater-6502-sbc-2.kicad_pcb, eater-6502-sbc-2.kicad_sch, eater-6502-sbc.kicad_pcb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]
2023-03-06 Finished rough layout and parts selection.
    [eater-6502-sbc-2.kicad_pcb, eater-6502-sbc-2.kicad_sch, extra.kicad_sch]
